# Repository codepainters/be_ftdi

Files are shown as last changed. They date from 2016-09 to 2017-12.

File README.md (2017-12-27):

Be\_FTDI
========

Simple `FT232H`-based USB interface for the great [BeMicro Max10](http://www.alterawiki.com/wiki/BeMicro_Max_10) FPGA board.  

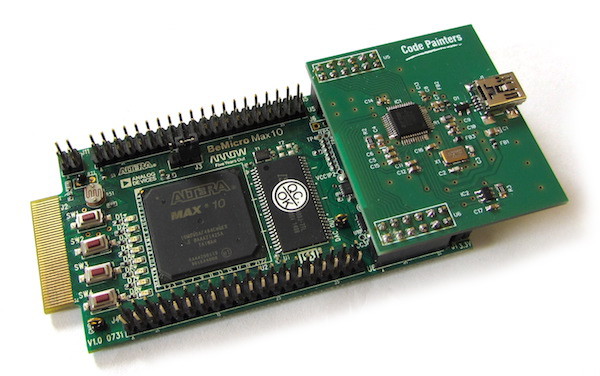
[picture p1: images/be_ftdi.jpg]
Be\_FTDI Logo


The interface uses `FTDI FT232H` in synchronous FIFO mode. Throughput achieved in testing:

 * PC (Ubuntu 16.04, kernel 4.4.0)  - 21.5 MB/s upstream (FPGA to PC), 31.2 MB/s downstream (PC to FPGA)
 * MacBook Pro (OS X 10.10.5) - 25.7 MB/s upstream, 37.6 MB/s downstream

See [tests](tests) directory for VHDL & C test code.

All the project files are licensed under Modified BSD License (see [LICENSE.txt](LICENSE.txt)).

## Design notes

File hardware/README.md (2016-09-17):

Be\_FTDI
========

This directory contains:

 * [DipTrace](http://diptrace.com/) schmatic and PCB files
 * Gerber/Excellon files
 * schematics PDF

Pin mapping
-----------

`FT232H` is connected to FPGA via PMOD headers U5 and U6.

| U5 Pin | FTDI | Be Micro port |
|---|---|---|
| 1 | D7 | PMOD\_A[0] |
| 2 | D6 | PMOD\_B[0] |
| 3 | D5 | PMOD\_A[1] |
| 4 | D4 | PMOD\_B[1] |
| 5 | D3 | PMOD\_A[2] |
| 6 | D2 | PMOD\_B[2] |
| 7 | D1 | PMOD\_A[3] |
| 8 | D0 | PMOD\_B[3] |

| U6 Pin | FTDI  | Be Micro port |
|---|---|---|
| 1 | ~TXE  | PMOD\_C[0] |
| 2 | ~RXF  | PMOD\_D[0] |
| 3 | ~WR | PMOD\_C[1] |
| 4 | ~RD | PMOD\_D[1] |
| 5 | CLK | PMOD\_C[2] |
| 6 | ~SIWU | PMOD\_D[2] |
| 8 | ~OE | PMOD\_D[3] |

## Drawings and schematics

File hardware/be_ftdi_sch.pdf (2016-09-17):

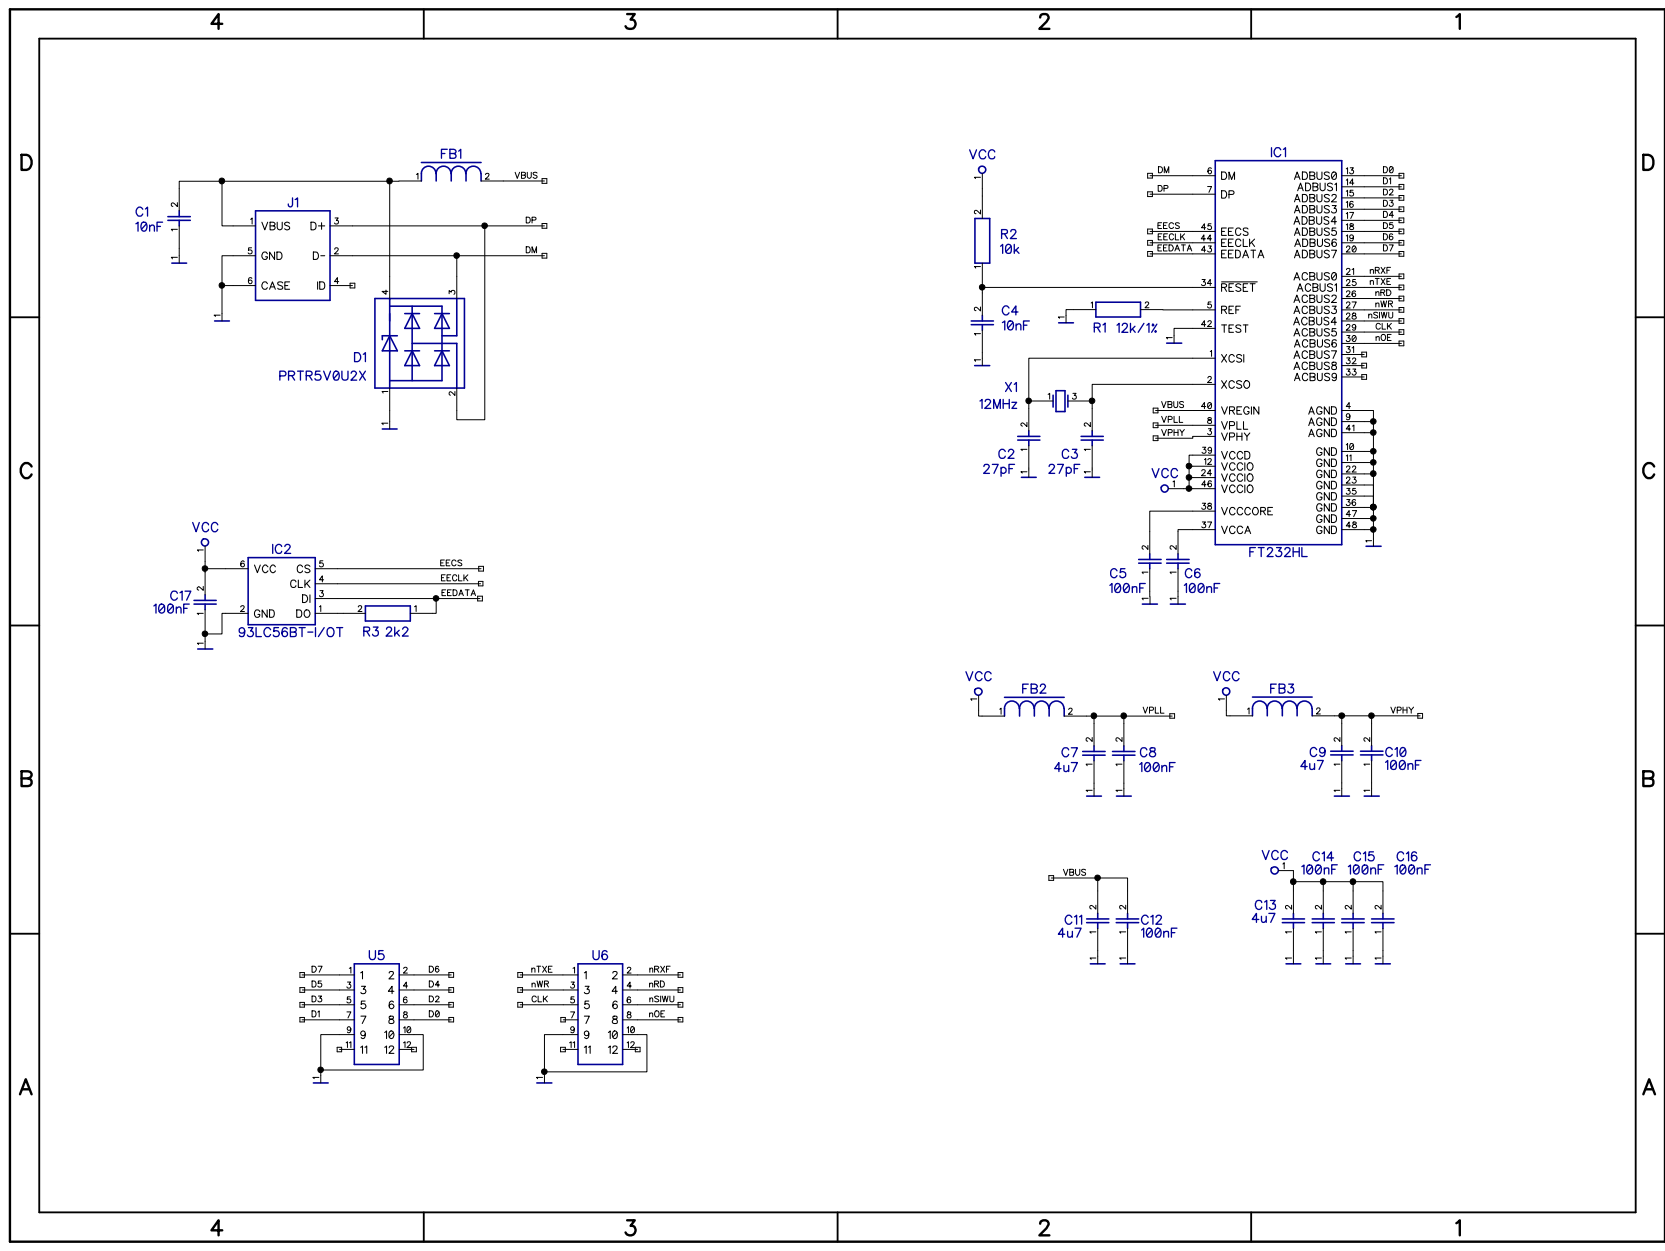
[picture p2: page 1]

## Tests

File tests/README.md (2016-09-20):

Be\_FTDI tests
==============

 * `fpga_ds` - Quartus II project (VHDL) for downstream (host -> FPGA) transfer test
 * `fpga_us` - Quartus II project (VHDL) for upstream (FPGA -> host) transfer test
 * `host` - host-side test code (cmake and libftdi required)

Host-side tests include the following binaries:

 * `bf_leds` - simple blinking LEDs write test (use with `fpga_us`)
 * `bf_rxfifo` - upstream transfer test (use with `fpga_us`)
 * `bf_txfifo` - downstream transfer test (use with `fpga_ds`)
 * `bf_eeprom_reset` - helper to reset configuration EEPROM contents

For upstream test FPGA sends a sequence of bytes which is verified by the host. Throughput/error statistics are printed on the console every 5 seconds, test continues until interrupted.

For downstream test host sends randomized data to FPGA, which calculates CRC8 and displays it on the board LEDs. CRC has to be compared "manually" with the expected value printed on the host console. Test continues until a given number of megabytes is transferred (command line argument).

For details see source code comments.

Note: the on-board EEPROM has to be programmed once before using the board using `FT_PROG` tool from FTDI. See the hardware folder.

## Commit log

2016-07-29 FTDI schematic lib
2016-07-29 Schematic - work in progress
2016-07-30 BeFTDI PCB initial component placement
2016-08-01 PCB - initial placement / routing attempt
2016-08-02 PCB - everything but GND routed
2016-08-02 PCB routing completed
2016-08-08 Gerbers / Excellon
    [bftdi.drl, bftdi_BoardOutline.gbr, bftdi_Bottom.gbr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]
2016-08-26 README added with pin mapping
2016-09-13 test: LEDs reverted to show byte written
2016-09-14 LEDs - use positive logic
2016-09-17 Schematic PDF
2016-09-23 Board picture added
